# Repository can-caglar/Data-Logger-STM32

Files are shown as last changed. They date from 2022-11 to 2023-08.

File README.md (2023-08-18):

# Serial Snooper

The Serial Snooper is a UART data logger with automatic baud rate detection, real-time data stamping and a command-line-interface for configuration, running on an STM32F3 microcontroller.

It is utilised in an R&D setting to easily capture logs from devices to speed up catching software and hardware bugs.

<i> This project started out as a submission for the final project in the course "Making Embedded Systems" by Elecia White, and evolved into a complete functional product used professionally. The report for the project submitted to the course can be found [here](https://docs.google.com/document/d/1QN5CVr99LwbAlFGOjgETou2btL8RMqJVu_yTGeXLMHs/edit?usp=sharing). </i>

## The Final Product

<center>
<image src="resource\hw_image_1.jpg">
<i>PCBA Front</i>
<br>
<br>
<image src="resource\hw_image_2.jpg">
<i>PCBA Back</i>
<br>
<br>
</center>

## Description of Operation

1. Plug in USB (5V - resettable fuse limits current to 500mA incase of short circuits damaging the power source).
2. Device powers up, indicated by the green LED.
3. A short moment later, the red LED lights up, indicating that the SD card was successfully initialised.
4. Plug in DB9 cable for the device you wish to snoop. The baud rate will be automatically detected.
5. The yellow LED will toggle for every character received.
6. The blue LED will toggle for every successful SD card write.
7. When ready, power down the device by removing the USB cable and remove the SD card.

## Schematic

<center>
<image src="HardwareDesign\hardwareImages_v1\schematic_png.PNG">
<i>Partial schematic. At the heart of the device is a STM32F303 microcontroller.</i>
</center>
<br>

The full hardware schematic can be found on [Github](HardwareDesign/hardwareImages_v1/serial_snooper_schematic.pdf).

## Design Block Diagram

<center>
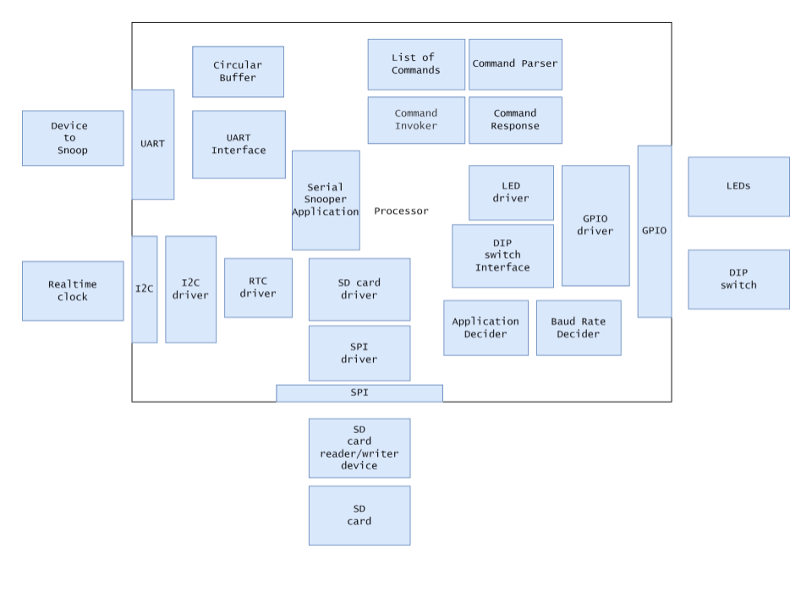
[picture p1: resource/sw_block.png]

<i>Software Block Diagram</i>
</center>

## Prototype

A prototype board was created to aid development.

Headers have been soldered to a perforated board. A mixture of wire wrapping and soldering used for the connections.

### The working prototype

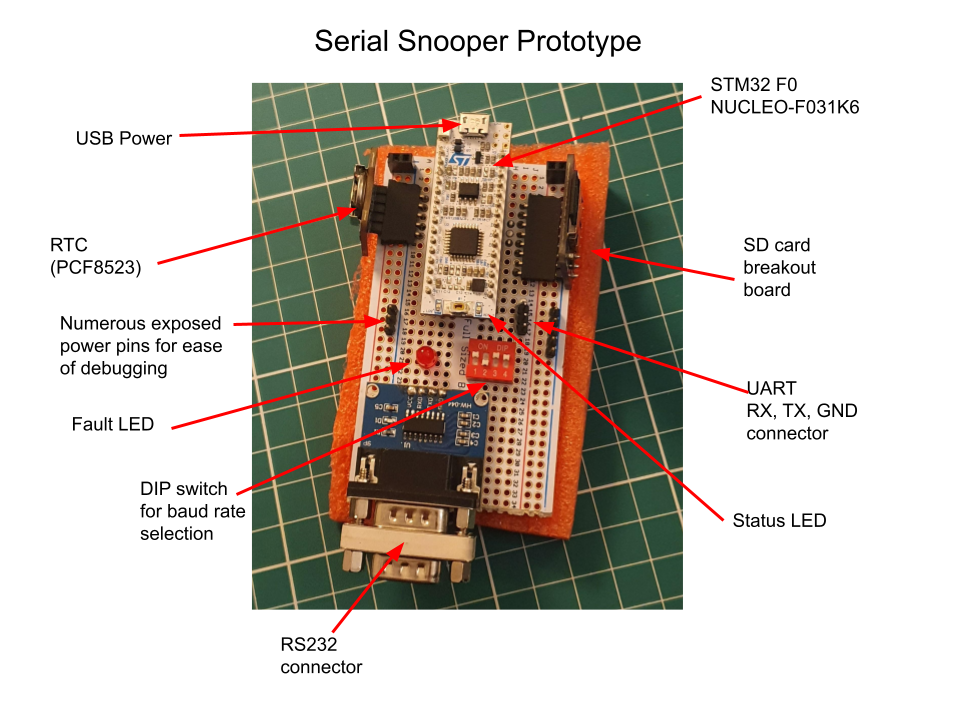
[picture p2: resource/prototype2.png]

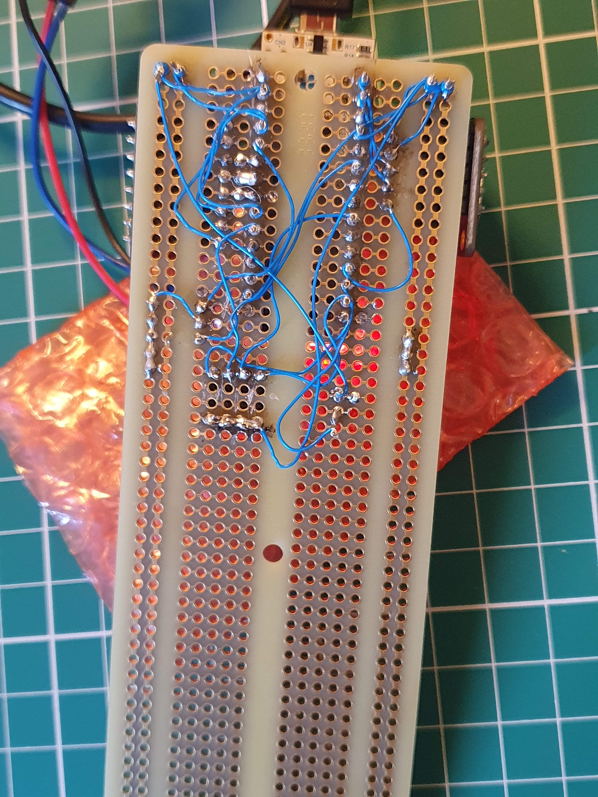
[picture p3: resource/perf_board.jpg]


### Pinouts

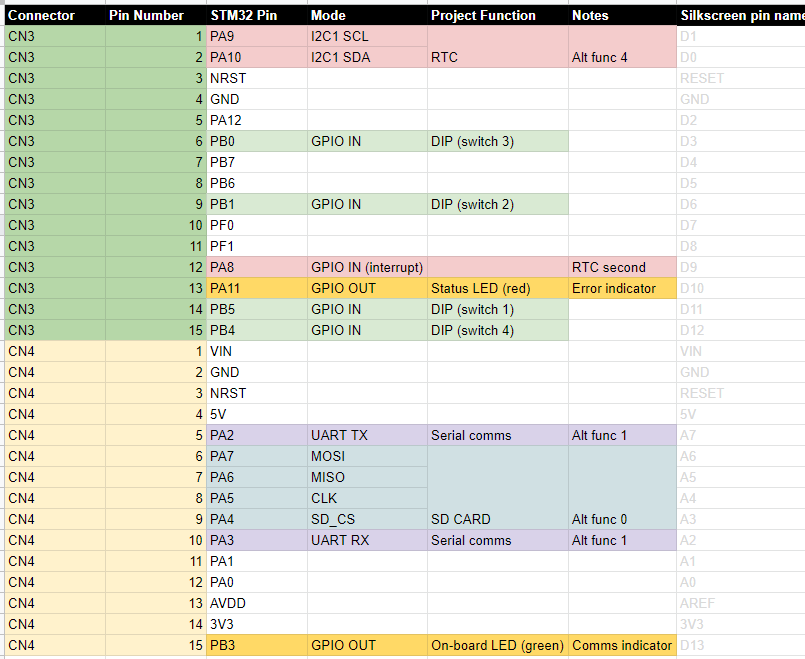
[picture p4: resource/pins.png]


# Demo 

All demonstrations below are from the prototype device using the software in this repository.

## Command Line Interface (CLI)

The CLI is used to:

- Ascertain the software version number
- Send commands:
  - Get DIP switch setting.
  - Get the current time.
  - Set the current time.

For example:
<center>
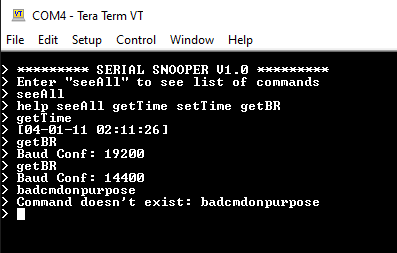
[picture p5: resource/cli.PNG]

</center>

## Example Data Saved on SD Card

The received data is timestamped and saved to the SD card. The filesystem being used is Fatfs (middleware software for this was provided by STM32 Cube).

In the example below, nearly 30,000 characters were sent over the course of 68 seconds (at 115200 BR) and all data was transferred successfully.

*(The text file below is generated by the Serial Snooper and can be found as resource/example_log.TXT)*

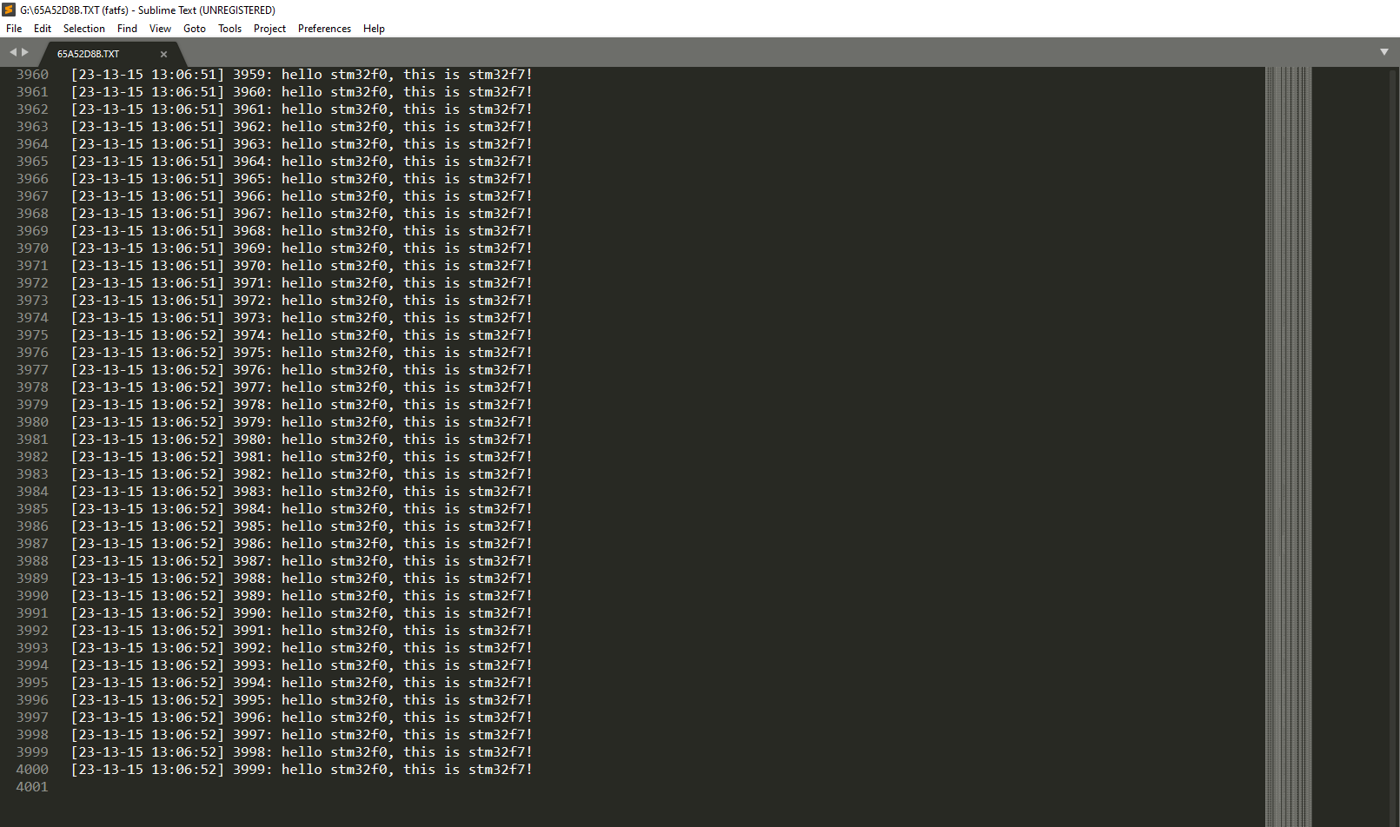
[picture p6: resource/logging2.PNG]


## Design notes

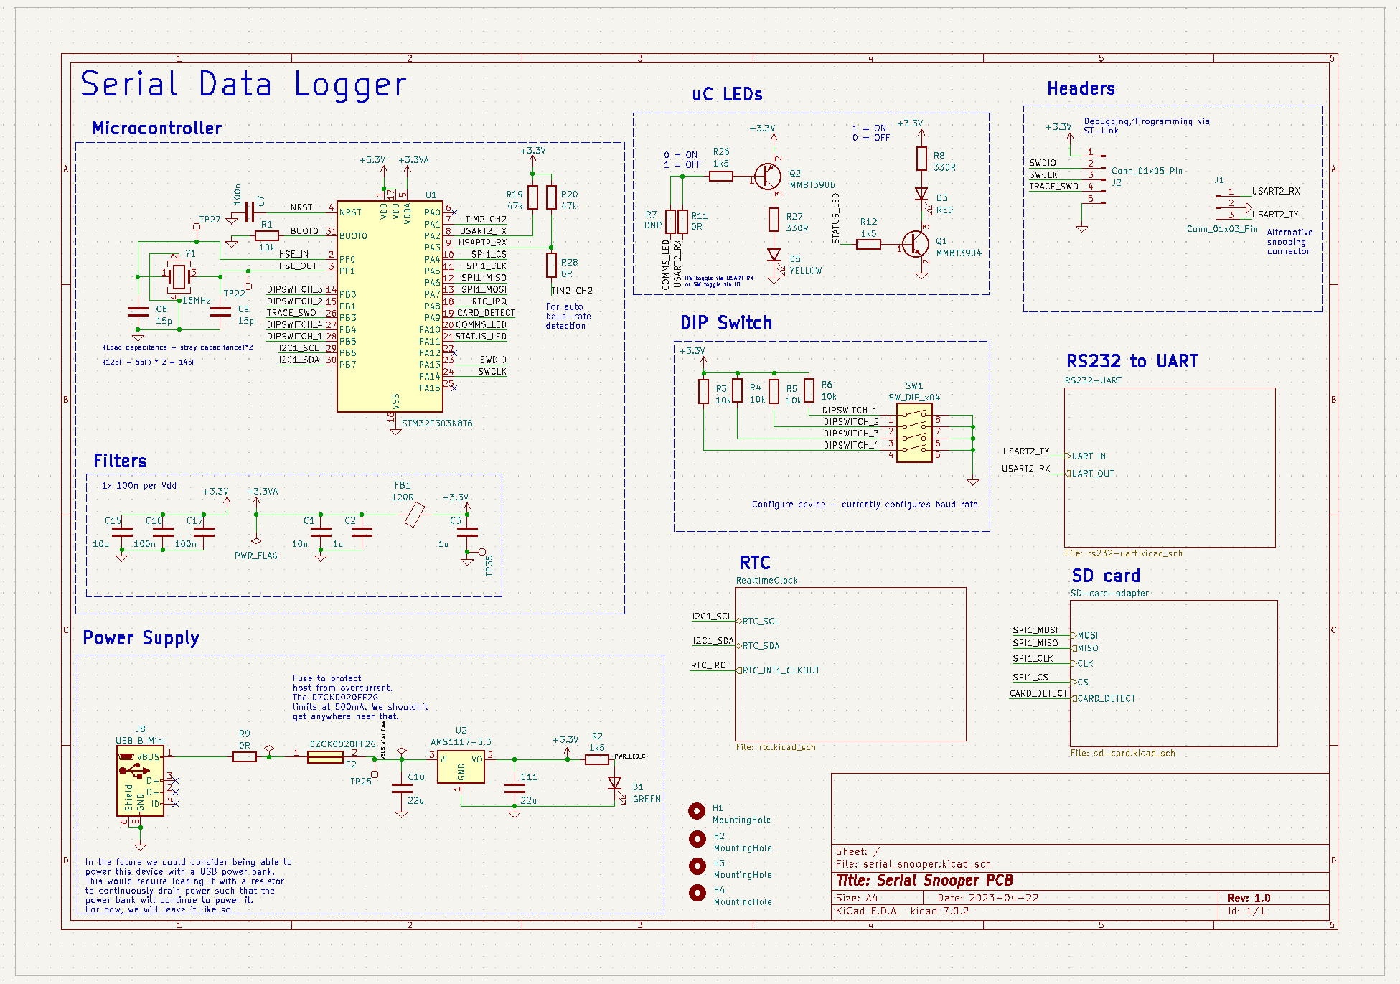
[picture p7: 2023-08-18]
HardwareDesign/hardwareImages_v1/schematic_png.PNG

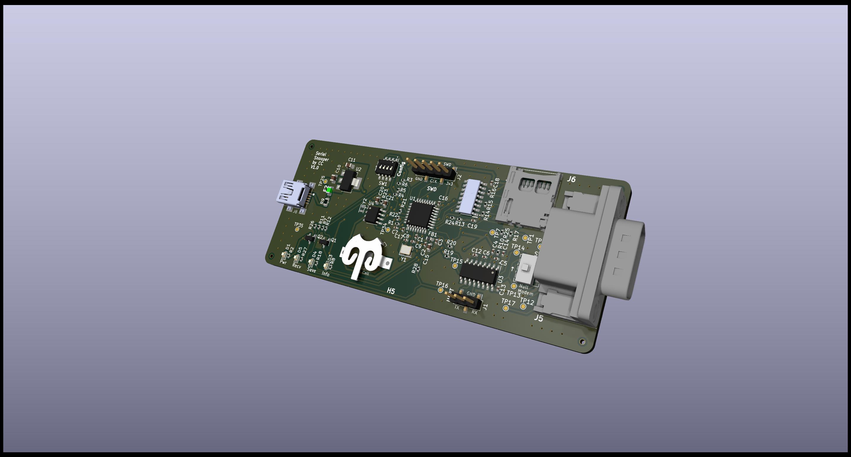
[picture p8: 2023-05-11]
HardwareDesign/hardwareImages_v1/serial_snooper_physical_board.jpg

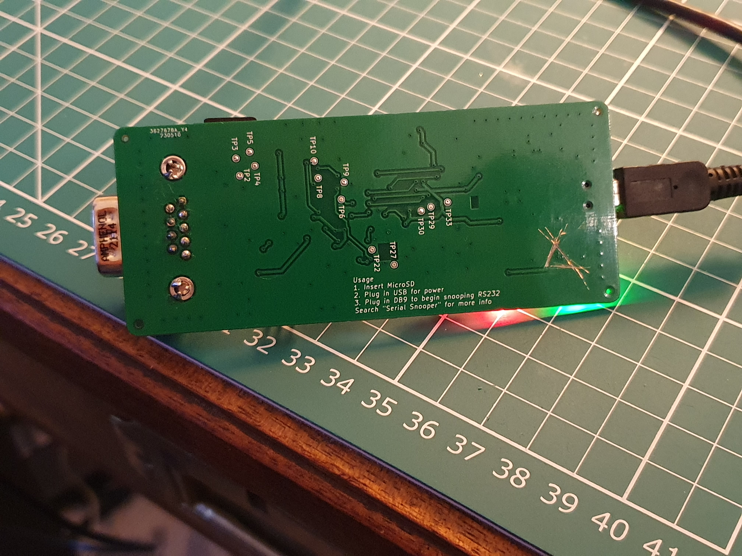
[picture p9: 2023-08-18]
resource/hw_image_2.jpg

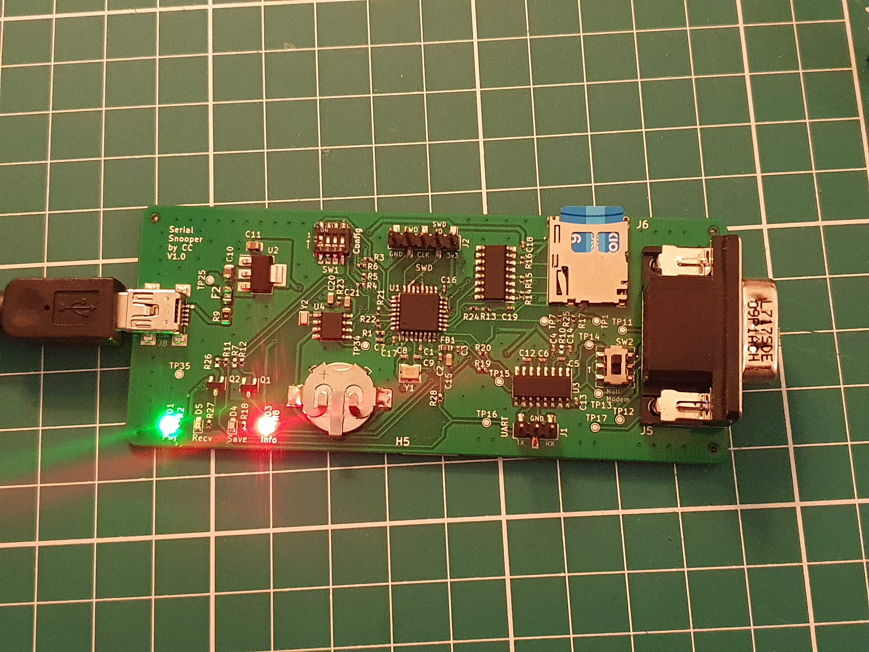
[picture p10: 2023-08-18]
resource/hw_image_1.jpg

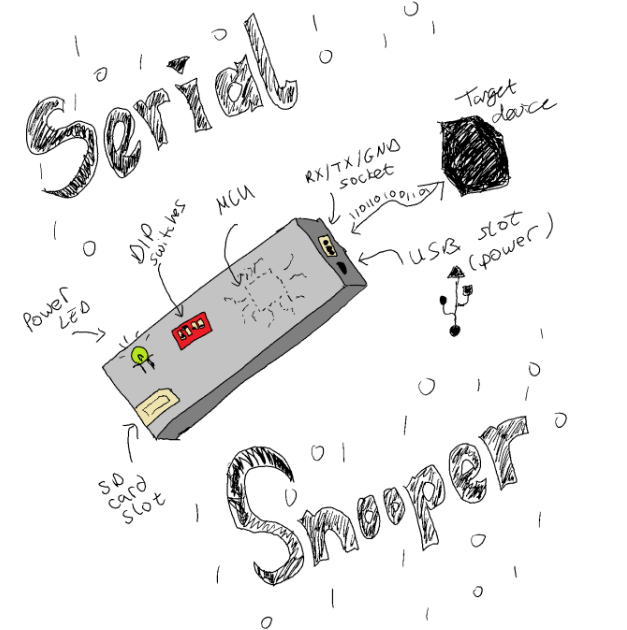
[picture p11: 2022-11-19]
resource/serial_snooper.png

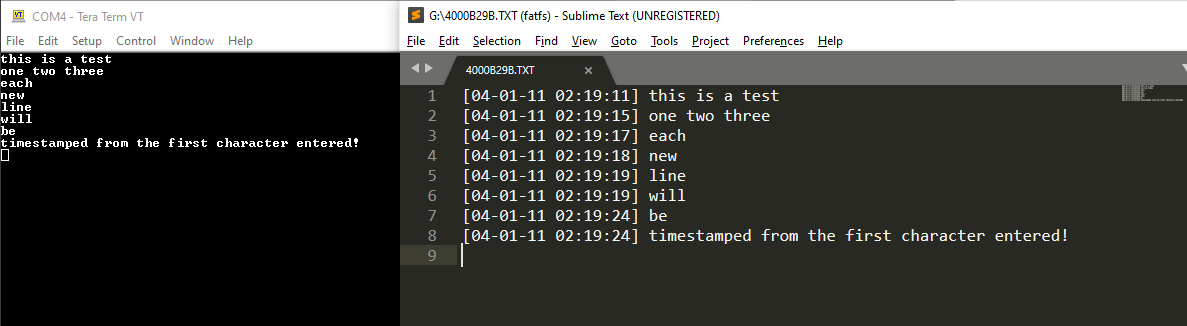
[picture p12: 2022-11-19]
resource/logging.PNG

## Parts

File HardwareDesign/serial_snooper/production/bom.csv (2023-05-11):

Designator | Footprint | Quantity | Value | LCSC Part #
C1 | 0402 | 1 | 10n
C10, C11 | 0805 | 2 | 22u
C12, C13, C14, C16, C17, C18, C19, C4, C5, C6, C7 | 0402 | 11 | 100n
C15, C20, C21 | 0603 | 3 | 10u
C2, C3 | 0402 | 2 | 1u
C8, C9 | 0402 | 2 | 15p
D1 | 0603 | 1 | GREEN
D3 | 0603 | 1 | RED
D4 | 0603 | 1 | RED_SD
D5 | 0603 | 1 | YELLOW
F2 | FUSC2214X100N | 1 | 0ZCK0020FF2G
FB1 | 0603 | 1 | 120R
H1, H2, H3, H4 | ToolingHole | 4 | MountingHole
H5 | 2894 | 1 | 2894
IC1 | SOIC127P600X175-16N | 1 | 74HC4050D,653 | C43181
J1 | PinHeader_1x03_P2.54mm_Vertical_SMD_Pin1Left | 1 | Conn_01x03_Pin | C5160786
J2 | PinHeader_1x05_P2.54mm_Vertical_SMD_Pin1Left | 1 | Conn_01x05_Pin
J5 | L717SDE09P1ACH | 1 | L717SDE09P1ACH
J6 | 5025700893 | 1 | Micro_SD_Card_Det1 | C429846
J8 | USB-MINI-10033526-N3212LF | 1 | USB_B_Mini | C428494
Q1 | SOT-23 | 1 | MMBT3904
Q2 | SOT-23 | 1 | MMBT3906
R1, R21, R22, R3, R4, R5, R6 | 0402 | 7 | 10k
R10, R7 | 0402 | 2 | DNP
R11, R24, R25, R28 | 0402 | 4 | 0R
R12, R18, R2, R23, R26 | 0402 | 5 | 1k5
R13, R14, R15, R16, R17, R19, R20 | 0402 | 7 | 47k
R27, R8 | 0402 | 2 | 330R
R9 | 0805 | 1 | 0R
SW1 | SW_DIP_SPSTx04_Slide_Omron_A6H-4101_W6.15mm_P1.27mm | 1 | SW_DIP_x04
SW2 | DPDT-SMD-MS-22D28G2-B | 1 | SW_DPDT_x2 | C2939266
TP1, TP10, TP11, TP12, TP13, TP14, TP15, TP16, TP17, TP2, TP22, TP25, TP27, TP29, TP3, TP30, TP33, TP34, TP35, TP4, TP5, TP6, TP7, TP8, TP9 | TestPoint_Pad_D1.0mm | 25 | TestPoint
U1 | LQFP-32_7x7mm_P0.8mm | 1 | STM32F303K8T6 | C118318
U2 | SOT-223-3_TabPin2 | 1 | AMS1117-3.3 | C351784
U3 | SOIC-16_3.9x9.9mm_P1.27mm | 1 | MAX3232 | C193666
U4 | SOIC-8_3.9x4.9mm_P1.27mm | 1 | PCF8523T | C2651516
Y1 | Crystal_SMD_3225-4Pin_3.2x2.5mm | 1 | 16MHz | C279610
Y2 | Crystal_SMD_2012-2Pin_2.0x1.2mm | 1 | 32.768 | C252397

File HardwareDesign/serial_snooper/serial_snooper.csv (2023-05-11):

Source: | C:\Users\canca\OneDrive\Study\Embedded\tdd_embedded_systems\on_target_3\HardwareDesign\serial_snooper\serial_snooper.kicad_sch
Date: | 08/05/2023 15:58:42
Tool: | Eeschema 7.0.2
Generator: | C:\Program Files\KiCad\7.0\bin\scripting\plugins/bom_csv_grouped_by_value_with_fp.py
Component Count: | 101
Ref | Qnty | Value | Cmp name | Footprint | Description | Vendor | DNP
C1 | 1 | 10n | C | Capacitor_SMD:C_0402_1005Metric | Unpolarized capacitor
C2, C3 | 2 | 1u | C | Capacitor_SMD:C_0402_1005Metric | Unpolarized capacitor
C4, C5, C6, C7, C12, C13, C14, C16, C17, C18, C19 | 11 | 100n | C | Capacitor_SMD:C_0402_1005Metric | Unpolarized capacitor
C8, C9 | 2 | 15p | C | Capacitor_SMD:C_0402_1005Metric | Unpolarized capacitor
C10, C11 | 2 | 22u | C | Capacitor_SMD:C_0805_2012Metric | Unpolarized capacitor
C15, C20, C21 | 3 | 10u | C | Capacitor_SMD:C_0603_1608Metric | Unpolarized capacitor
D1 | 1 | GREEN | LED | LED_SMD:LED_0603_1608Metric | Light emitting diode
D3 | 1 | RED | LED | LED_SMD:LED_0603_1608Metric | Light emitting diode
D4 | 1 | RED_SD | LED | LED_SMD:LED_0603_1608Metric | Light emitting diode
D5 | 1 | YELLOW | LED | LED_SMD:LED_0603_1608Metric | Light emitting diode
F2 | 1 | 0ZCK0020FF2G | 0ZCK0020FF2G | MyLibrary:FUSC2214X100N | BEL FUSE - 0ZCK0020FF2G - FUSE, RESETTABLE PTC, 9VDC, 0.2A, SMD
FB1 | 1 | 120R | FerriteBead | Inductor_SMD:L_0603_1608Metric | Ferrite bead
H1, H2, H3, H4 | 4 | MountingHole | MountingHole | MountingHole:MountingHole_2.2mm_M2 | Mounting Hole without connection
H5 | 1 | 2894 | 2894 | MyLibrary:2894 | Coin Cell Battery Holders CR1220 COIN CELL SMT RETAINER
IC1 | 1 | 74HC4050D,653 | 74HC4050D,653 | MyLibrary:SOIC127P600X175-16N | NEXPERIA - 74HC4050D,653 - LEVEL SHIFTER, NON INVERTING, SOIC-16
J1 | 1 | Conn_01x03_Pin | Conn_01x03_Pin | Connector_PinHeader_2.54mm:PinHeader_1x03_P2.54mm_Vertical_SMD_Pin1Left | Generic connector, single row, 01x03, script generated
J2 | 1 | Conn_01x05_Pin | Conn_01x05_Pin | Connector_PinHeader_2.54mm:PinHeader_1x05_P2.54mm_Vertical_SMD_Pin1Left | Generic connector, single row, 01x05, script generated
J5 | 1 | L717SDE09P1ACH | L717SDE09P1ACH | MyLibrary:L717SDE09P1ACH | Dsub, Stamped Signal 3A, Right Angle PCB Through Hole, FP=10.40mm (0.409in), Row Pitch 2.54mm, 9 Pin, Flash Gold, Bright Tin Shell+Grounding Dimples, 3.05mm (0.120in) Clear Hole, Ground Tab with Boardlock
J6 | 1 | Micro_SD_Card_Det1 | Micro_SD_Card_Det1 | MyLibrary:5025700893 | Micro SD Card Socket with one card detection pin
J8 | 1 | USB_B_Mini | USB_B_Mini | MyLibrary:USB-MINI-10033526-N3212LF | USB Mini Type B connector
Q1 | 1 | MMBT3904 | MMBT3904 | Package_TO_SOT_SMD:SOT-23 | 0.2A Ic, 40V Vce, Small Signal NPN Transistor, SOT-23
Q2 | 1 | MMBT3906 | MMBT3906 | Package_TO_SOT_SMD:SOT-23 | -0.2A Ic, -40V Vce, Small Signal PNP Transistor, SOT-23
R1, R3, R4, R5, R6 | 5 | 10k | R | Resistor_SMD:R_0402_1005Metric | Resistor
R2, R12, R18, R23, R26 | 5 | 1k5 | R | Resistor_SMD:R_0402_1005Metric | Resistor
R7, R10 | 2 | DNF | R | Resistor_SMD:R_0402_1005Metric | Resistor
R8, R27 | 2 | 330R | R | Resistor_SMD:R_0402_1005Metric | Resistor
R9 | 1 | 0R | R | Resistor_SMD:R_0805_2012Metric | Resistor
R11, R24, R25, R28 | 4 | 0R | R | Resistor_SMD:R_0402_1005Metric | Resistor
R13, R14, R15, R16, R17, R19, R20 | 7 | 47k | R | Resistor_SMD:R_0402_1005Metric | Resistor
R21, R22 | 2 | 10K | R | Resistor_SMD:R_0402_1005Metric | Resistor
SW1 | 1 | SW_DIP_x04 | SW_DIP_x04 | Button_Switch_SMD:SW_DIP_SPSTx04_Slide_Omron_A6H-4101_W6.15mm_P1.27mm | 4x DIP Switch, Single Pole Single Throw (SPST) switch, small symbol
SW2 | 1 | SW_DPDT_x2 | SW_DPDT_x2 | MyLibrary:DPDT-SMD-MS-22D28G2-B | Switch, dual pole double throw, separate symbols
TP1, TP2, TP3, TP4, TP5, TP6, TP7, TP8, TP9, TP10, TP11, TP12, TP13, TP14, TP15, TP16, TP17, TP22, TP25, TP27, TP29, TP30, TP33, TP34, TP35 | 25 | TestPoint | TestPoint | TestPoint:TestPoint_Pad_D2.0mm | test point
U1 | 1 | STM32F303K8T6 | STM32F303K8Tx | Package_QFP:LQFP-32_7x7mm_P0.8mm | STMicroelectronics Arm Cortex-M4 MCU, 64KB flash, 16KB RAM, 72 MHz, 2.0-3.6V, 25 GPIO, LQFP32
U2 | 1 | AMS1117-3.3 | AMS1117-3.3 | Package_TO_SOT_SMD:SOT-223-3_TabPin2 | 1A Low Dropout regulator, positive, 3.3V fixed output, SOT-223
U3 | 1 | MAX3232 | MAX3232 | Package_SO:SOIC-16_3.9x9.9mm_P1.27mm | 3.0V to 5.5V, Low-Power, up to 1Mbps, True RS-232 Transceivers Using Four 0.1μF External Capacitors
U4 | 1 | PCF8523T | PCF8523T | Package_SO:SOIC-8_3.9x4.9mm_P1.27mm | Realtime Clock/Calendar I2C Interface, SOIC-8
Y1 | 1 | 16MHz | Crystal_GND24 | Crystal:Crystal_SMD_3225-4Pin_3.2x2.5mm | Four pin crystal, GND on pins 2 and 4
Y2 | 1 | 32.768 | Crystal | Crystal:Crystal_SMD_2012-2Pin_2.0x1.2mm | Two pin crystal

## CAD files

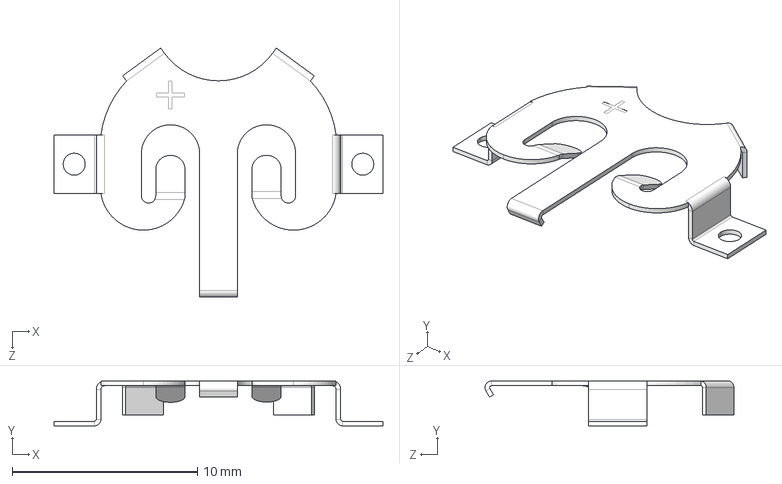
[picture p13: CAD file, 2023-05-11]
HardwareDesign/serial_snooper/CR1220_CASE_LIB_2894/2894/3D/2894.stp
17.8 x 2.42 x 13.5 mm

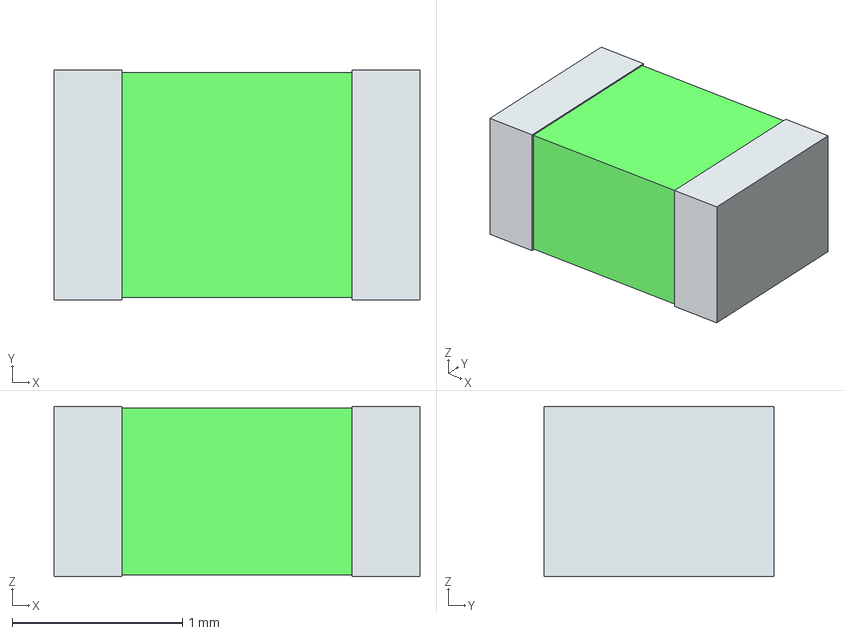
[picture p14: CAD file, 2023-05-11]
HardwareDesign/serial_snooper/LIB_0ZCK0020FF2G/0ZCK0020FF2G/3D/0ZCK0020FF2G.stp
2.15 x 1.35 x 1.00 mm
term1
term2

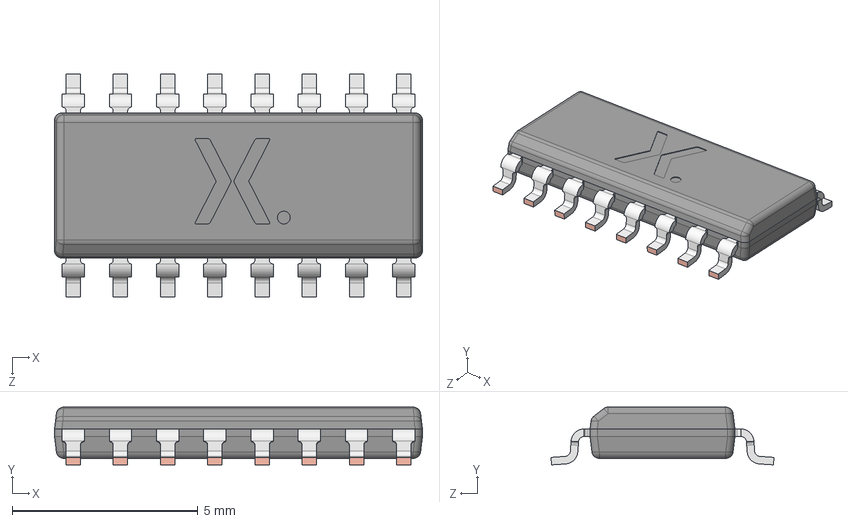
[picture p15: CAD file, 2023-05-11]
HardwareDesign/serial_snooper/LIB_74HC4050D,653/74HC4050D,653/3D/74HC4050D,653.stp
9.90 x 1.56 x 6.00 mm
SOT109-1 lower body
SOT109-1 upper body
SOT109-1 Lead

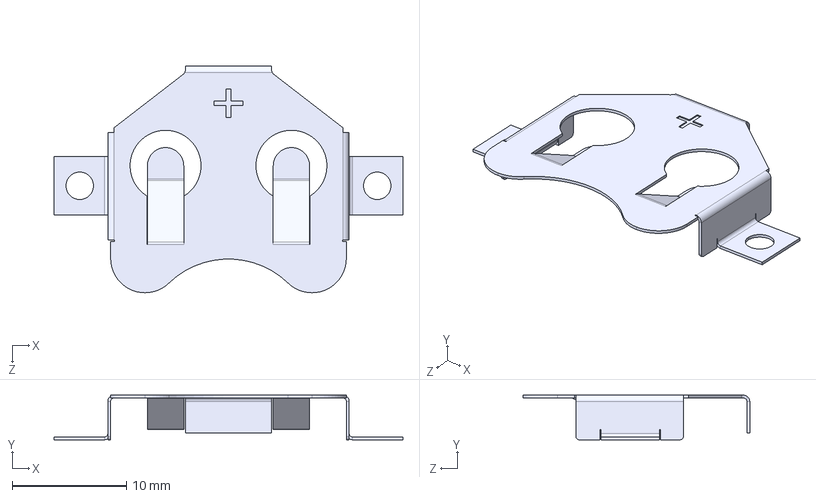
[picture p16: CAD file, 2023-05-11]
HardwareDesign/serial_snooper/LIB_BAT-HLD-003-SMT/BAT-HLD-003-SMT--3DModel-STEP-1.STEP
30.5 x 3.90 x 19.8 mm

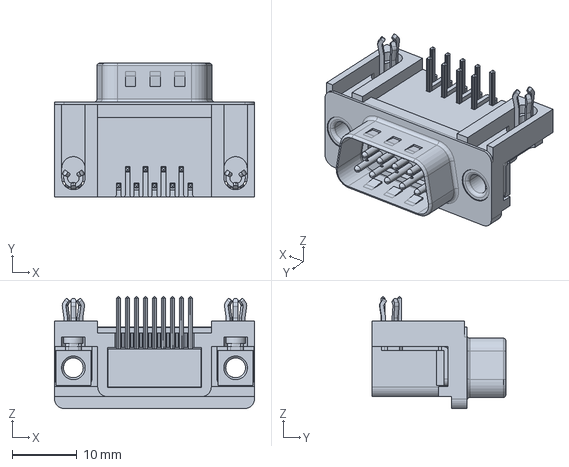
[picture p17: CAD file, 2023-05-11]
HardwareDesign/serial_snooper/LIB_L717SDE09P1ACH/L717SDE09P1ACH/3D/L717SDE09P1ACH.stp
30.8 x 20.6 x 17.3 mm

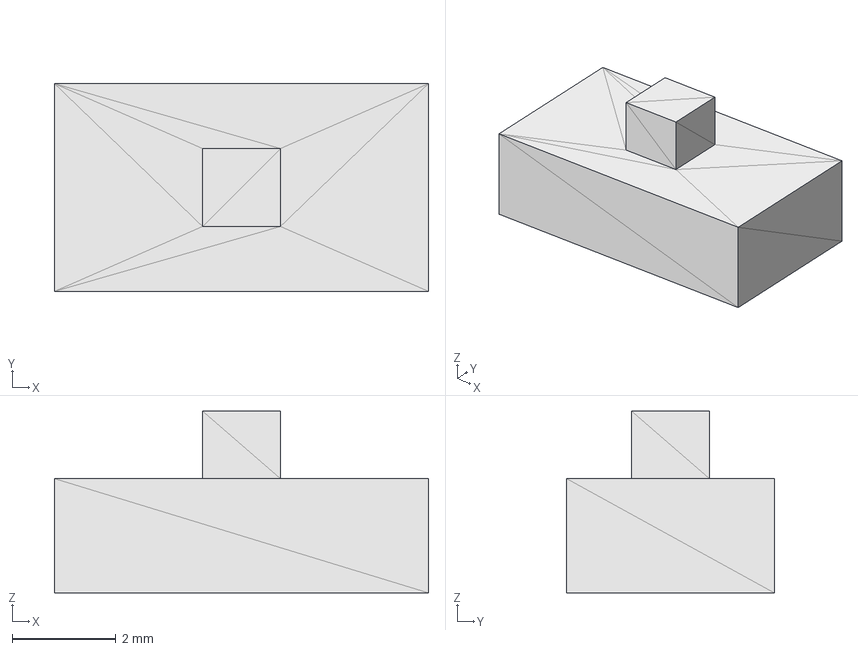
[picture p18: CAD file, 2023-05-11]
HardwareDesign/serial_snooper/DPDT_22D28G2-B/a.step
7.20 x 4.00 x 3.50 mm

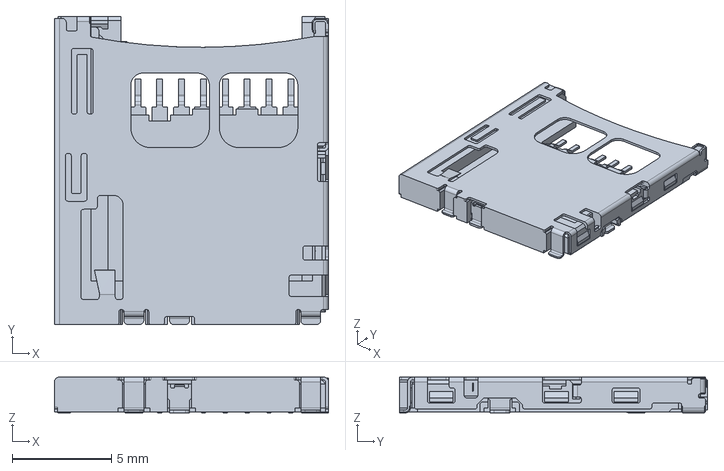
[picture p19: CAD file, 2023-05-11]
HardwareDesign/serial_snooper/LIB_502570-0893/502570-0893/3D/502570-0893.stp
13.8 x 15.5 x 1.80 mm

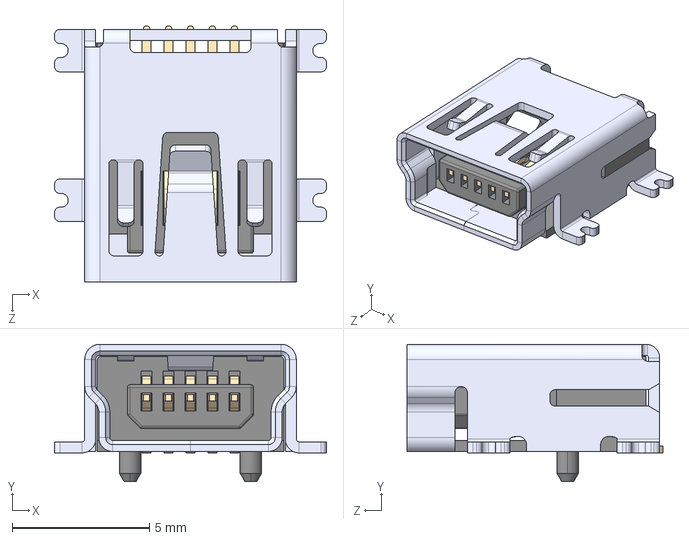
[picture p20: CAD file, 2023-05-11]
HardwareDesign/serial_snooper/USB_Mini/10033526-N3212LF--3DModel-STEP-554624.STEP
9.90 x 5.00 x 9.32 mm

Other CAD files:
HardwareDesign/serial_snooper/DPDT_22D28G2-B/DPDT SW 22D28G2-B.stp
HardwareDesign/serial_snooper/DPDT_22D28G2-B/dpdt_3d.stp
HardwareDesign/serial_snooper/CR1220_CASE_LIB_2894/2894/Allegro/2894.psm
HardwareDesign/serial_snooper/CR1220_CASE_LIB_2894/2894/DEHDL/2894/chips/chips.prt
HardwareDesign/serial_snooper/DPDT_22D28G2-B/DPDT SW 22D28G2-B.stl
HardwareDesign/serial_snooper/LIB_0ZCK0020FF2G/0ZCK0020FF2G/Allegro/fusc2214x100n.psm
HardwareDesign/serial_snooper/LIB_0ZCK0020FF2G/0ZCK0020FF2G/DEHDL/0zck0020ff2g/chips/chips.prt
HardwareDesign/serial_snooper/LIB_502570-0893/502570-0893/Allegro/5025700893.psm
HardwareDesign/serial_snooper/LIB_502570-0893/502570-0893/DEHDL/502570_0893/chips/chips.prt
HardwareDesign/serial_snooper/LIB_74HC4050D,653/74HC4050D,653/Allegro/soic127p600x175-16n.psm
HardwareDesign/serial_snooper/LIB_74HC4050D,653/74HC4050D,653/DEHDL/74hc4050d_653/chips/chips.prt
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

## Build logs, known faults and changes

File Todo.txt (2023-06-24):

***************************************************************************************************************************************************

# Data Logger V2 Tasks:

- [ ] Variable names (namely make MVC pattern more obvious)
- [x] Reduce size of program
- [x] Do not read circ buf if it's empty
- [x] Remove context argument from data holder, it doesn't need it
    - [x] Remove refresh too. and give data if/when requested
- [x] Upgrade uC so we can increase size of buffers
- [x] Understand fatfs better; it seems to buffer internally, 
    so perhaps writing 1 byte at a time is OK for performance
    - Benchmark shows the more we write, the faster the throughput.
- [x] Upgrade processor to one with more RAM.
    - [x] Update processor speed
    - [x] Update SPI speed
    - [x] Increase circular buffer size
    - [x] Update I2C wiring (PB7 SDA, PB6 SCL, AF4)
        - [!] Remove the solder bridge SB16 AND SB18 else I2C and SPI will clash.
    - [...] Remove solder bridge to allow the device to be plugged into the wall
        - Won't work as the current consumption with new processor and code is over 100mA (as per user manual)
        - Going to look into adding a separate connector.
    - [x] Update USART (usart1 -> usart2, new alt func)
    - [x] Check SD card library works
    - [x] Write a benchmarking test for the SD card - what is the write throughput?
        - Sending 1 byte per loop, vs 512, vs 1024, 2048, vs 4096
        - Turn off FF_FS_TINY?
        - Try higher SPI speed
        - Run the test a few times, perhaps 5 times each and get an average
    - [-] Use internal RTC | No VBAT on this particular chip (LQFP32)
        See page 31 LQFP32 pinout of STM32F303x6/x8 Datasheet for this info.
    - [x] Research baud rate detection
        - STM32F0, STM32F3 both have this feature
        - However, it requires the master device to send known bytes at the start.
        - Another way could be to wire RX line to a timer pin 
            with input capture. Take X measurements. 
            Smallest will likely be baud rate.
    - [-] Research the 4Kb of CCM RAM we have on this chip. | Currently do not need to
- [x] Update tests so they pass again with this new chip
- [x] Test circular buffer capacity that is not a power of 2 to make it as large as possible.
- [ ] Run an overnight test with a different SD card- does the buffer overflow?

***************************************************************************************************************************************************

Data logger V3 (current):

V2 behaviour: The Serial Snooper creates a log file on an SD card with a FAT32 file system. It will transfer UART received data 
to a file on the SD card until it reaches a max size. A new file is created when this happens. A new file is also created upon a power cycle.
UART baud rate is currently configured via DIP switches. 

New in V3: 
    - It will write to the same log file even after a power cycle.
        - Need a way to know to re-open the file it was writing to last. Details can change in future easily, as long as architecture is right.
            - Option 1: Since RTC has to work, we can just check the txt file that was written to last:
                - Making assumption that the SD card was only used by SS (if not, we risk writing to a log file not created by us)
            - Option 2: Save current log file name onto the SD card and retrieve on power cycle. If it doesn't exist, make a new one.
                - This will likely need to be expanded in the future to save more details that retain on a power cycle.
                - I.e. a file that holds a structure of data that needs to be parsed to get the information needed
            - Need an abstraction for log file creator. Handles opening a log file, let it handle where and what name.
            - Only 1 log file open at a time.
    - Make system behaviour more defined: Error handling:
        - We are making many assumptions. If any are not met, system may perform in inadvertant ways. Let's limit behaviour by calling error
            handling code if some conditions are not met.
        - Flash LED N number of times where N is number of LED blinks followed by a long delay, indefinitely.
        - Errors:
            - RTC not working, throw error - go to error handling code. 
            - If SD card not initialised, throw error - go to error handling code. Flash LED N number of times.
            - If SD card full

    - The name given to the log files: currently it's based on RTC time- an 8 digit unit timestamp in hex.
    - The naming convention of iterative log files: currently it's based on RTC but if RTC doesn't work it will keep opening the same 
        file even if max size reached. - solved by error handling code which won't let system work without RTC (for now)
    - Maximum number of log files - currently no maximum.
    - Whether or not there is a Maximum
    - What to do when the maximum log files is reached - shall be handled by error handling.
    - What happens if SD card contains too many files already, is full, or has files with our naming conventions?

- [x] Continue writing to the same file even after a power cycle
    - This gives the serial snooper a more predictable behaviour
    - Reduces likelihood of creating too many files on the SD card which may cause issues when reading it from a PC
    - [ ] Add system to retain information after power cycling and load this information on start-up.
- [ ] Add ability to configure the Serial Snooper via a config file on the SD card.
    - Max files
    - File circular buffer (oldest file gets re-written)
- [x] Auto-baud rate detection
    - Do this but fake the hardware dependency as I understand it
    - The technique is to connect uart input to a timer and interrupt on an edge
    - Look for the smallest time between the interrupts
        - to make it noise-proof, take a tally of these over a short period of time
    - this time will be the period

***************************************************************************************************************************************************

Data logger V4:

Behaviour: 
- We want the system to work even without an RTC.
- Let SD card be used by other things, not just SS?
- New configurable setting: Timestamping can be switched on or off. This is configured in the CLI and retained on the SD card.

Option 1:
    The logfiles should have a name that gives away which logfile was written to last.
        - The software can then parse the file names to get the last file.
        - This decouples the file naming from the RTC where in future if we want the system to work even if RTC power dies, it will work
        - Example: sslog000.txt, sslog001.txt, sslog002.txt ... sslog999.txt
        - Need an abstraction for the SD card storage itself where it knows which files are there, which configs etc?

***************************************************************************************************************************************************

Notes:
    - Where the log files are stored on the SD card: currently it's stored in root
        - abstractions:
            - which log file to write to
                - naming convention of log file: random? sequential?
            - directory of log file

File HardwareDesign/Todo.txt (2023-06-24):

- [x] Capture schematic
    - [x] Same as prototype version but without on-board ST link
        - [x] LED to indicate power
        - [x] LED to indicate receive (rx)
        - [x] LED to indicate transmit (tx)
        - [x] LED to indicate errors
        - [x] SWDIO for programming it
        - [x] Test points for comms
        - [x] Test points for GND
        - [x] USB for power only
        - [-] Power also from external supply?
        - [x] Current consumption header
        - [x] Pull up UART / SPI / I2C lines
        - [x] Use fuse for overcurrent protection
        - [x] Crystal, or crystal oscillator for stm32 uc
        - [x] Pins to expose UART
        - [x] USB mini
- [x] Draw layout
    - [-] Silkscreen
        - On the back, explain how to use it
- [x] Order
- [ ] Board bring-up
    - [x] Ensure 3v3 power led to lights up | there was an issue with the mask on the back plane causing a short (maybe forgot to do refill before
        generating gerbers). fixed it by cutting traces around the short.
    - [x] Program and debug the device | bad solder joints on the SWDIO and 3v3 line on the stm32 was causing issues. now it programs fine.
        - note: no reset line, but the system still seems to respect the reset button on Keil and start debugging from the beginning.
        - note2: the only pins connected are GND, SWDIO, SWCLK and 3v3 (to ST link pin 1 (Target Vcc).
    - [x] Set RTC time
        - [x] RTC doesn't retain time sometimes and resets, why? | the GND plane wasn't making contact with the battery - added
            solder there and now it's ok.
    - [ ] The "Save" LED (blue) doesn't light up - resistor val too high?
    - [x] Check soldering for the DIP switch - always returning 0xFF | was a bad solder joint
- [x] Code changes:
    - [x] No-pull on the dip switch I/O

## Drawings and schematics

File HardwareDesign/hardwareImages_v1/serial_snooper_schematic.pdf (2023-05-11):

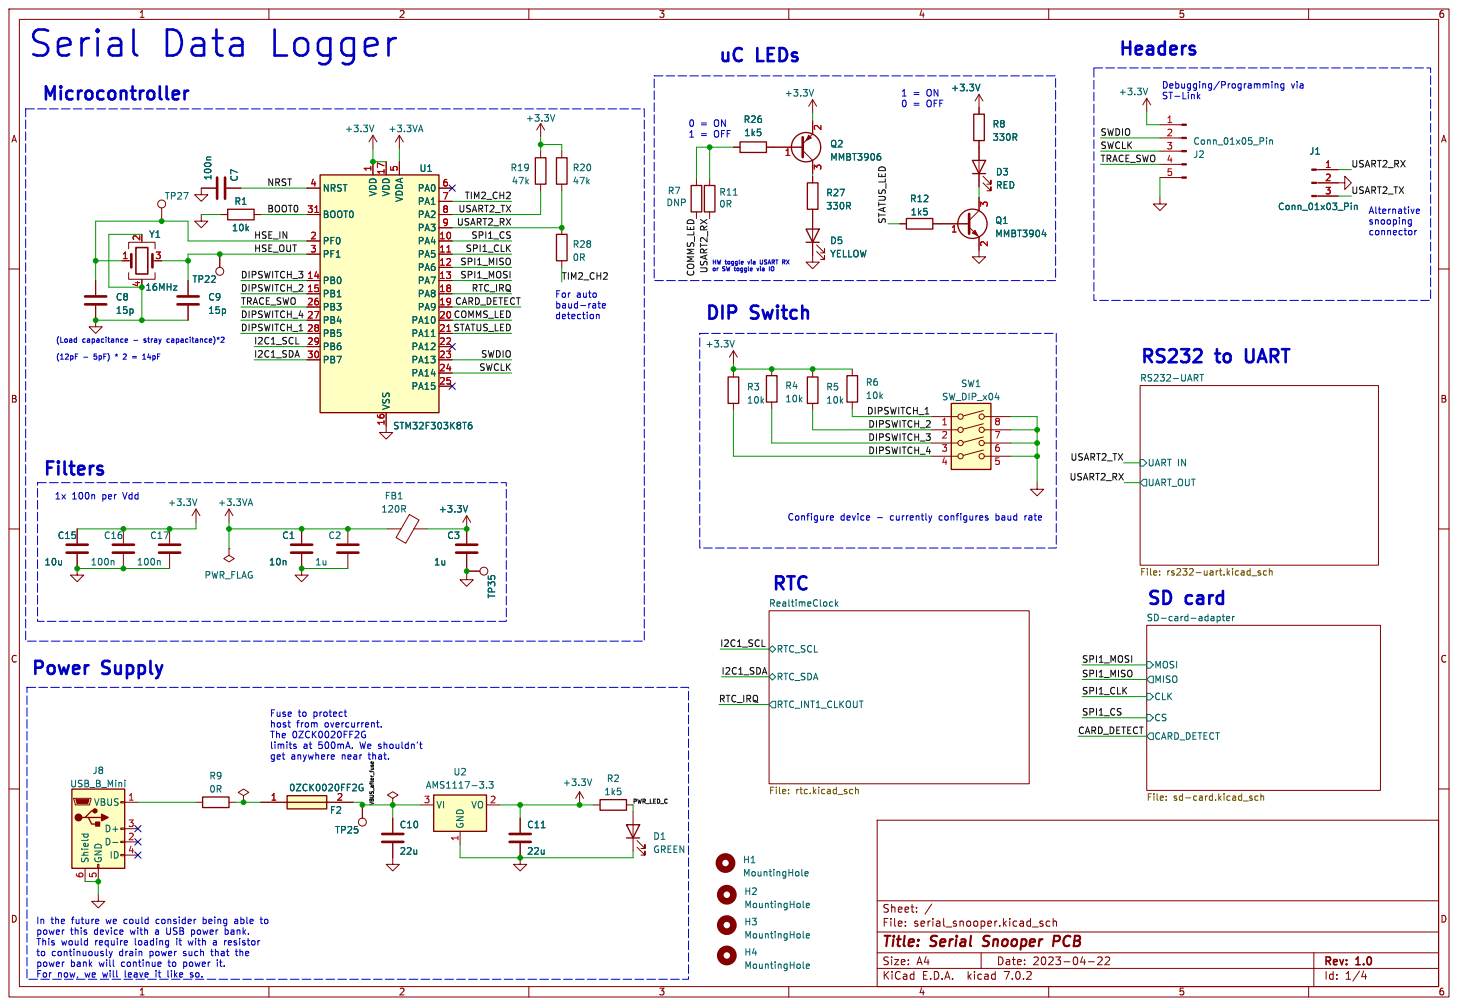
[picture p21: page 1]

1 = OFF Serial Data Logger

1 PA4 10 PA5 11 PA6 12 PA7 13 PB0 14 PB1 15 VSS 16 VDD 17 PA8 18 PA9 19 PF0 2 PA10 20 PA11 21 PA12 22 PA13 23 PA14 24 PA15 25 PB3 26 PB4 27 PB5 28 PB6 29 PF1 3 PB7 30 BOOT0 31 NRST 4 VDDA

HW toggle via USART RX

RS232-UART
CLK CSCARD_DETECT SD-card-adapter File: sd-card.kicad_sch UART_OUT UART IN

limits at 500mA. We shouldn't get anywhere near that. C1

File: rs232-uart.kicad_sch RTC_SCL RTC_INT1_CLKOUT RTC_SDA RealtimeClock File: rtc.kicad_sch

Fuse to protect host from overcurrent. The 0ZCK0020FF2G

In the future we could consider being able to
power this device with a USB power bank. This would require loading it with a resistor

Id: 1/4 Title: Serial Snooper PCB

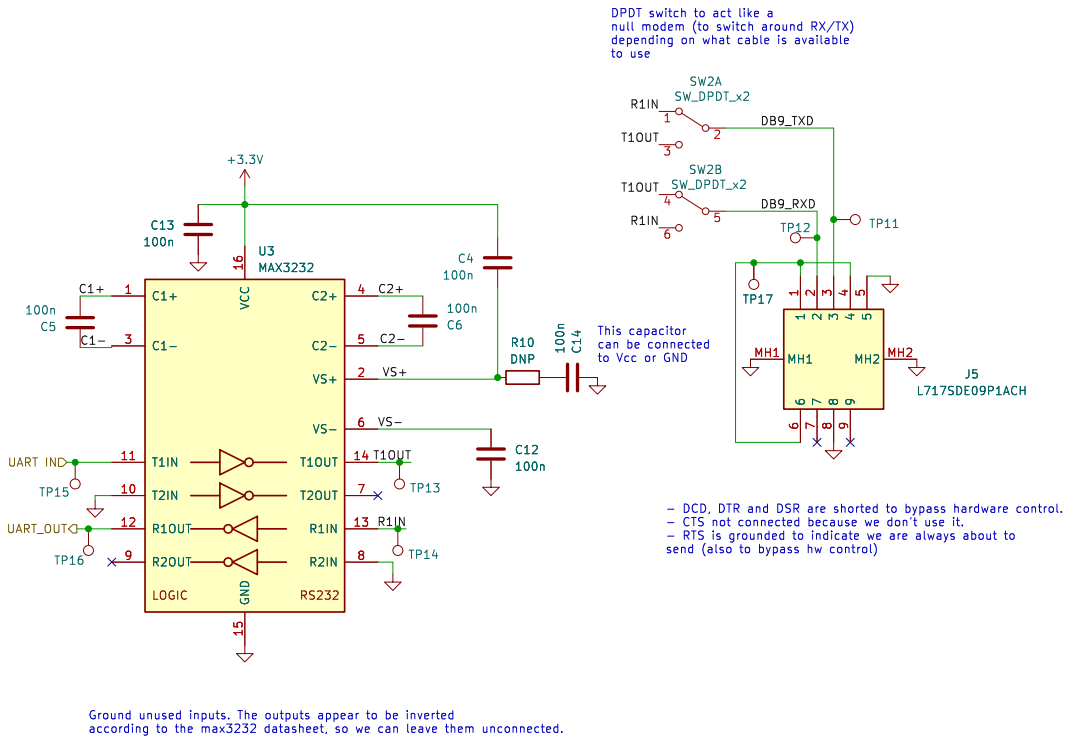
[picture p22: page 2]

send (also to bypass hw control) DPDT switch to act like a
null modem (to switch around RX/TX)
to use This capacitor can be connected

to Vcc or GND

Id: 2/4 Title: File: rs232-uart.kicad_sch Sheet: /RS232-UART/

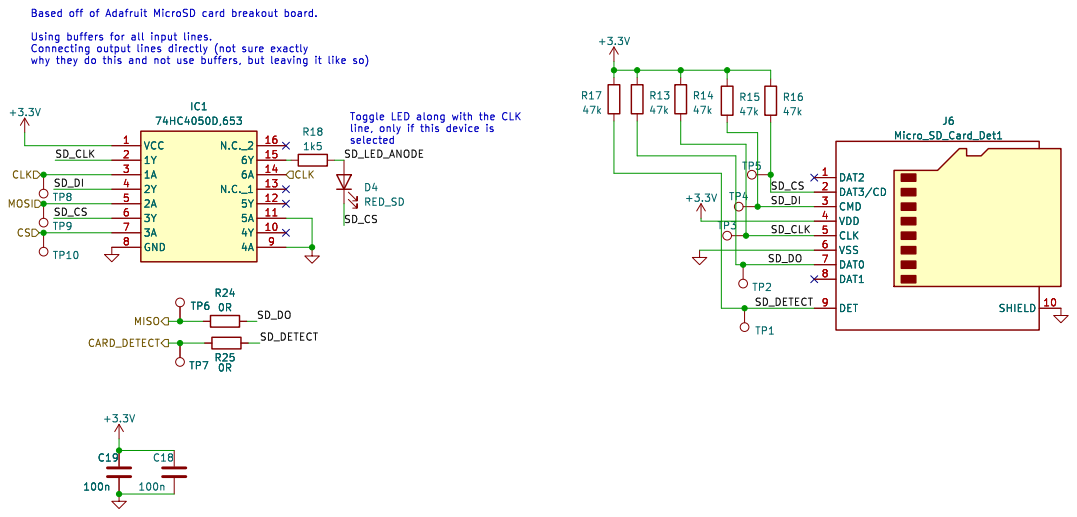
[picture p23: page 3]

Toggle LED along with the CLK
line, only if this device is

Id: 3/4 Title: File: sd-card.kicad_sch Sheet: /SD-card-adapter/

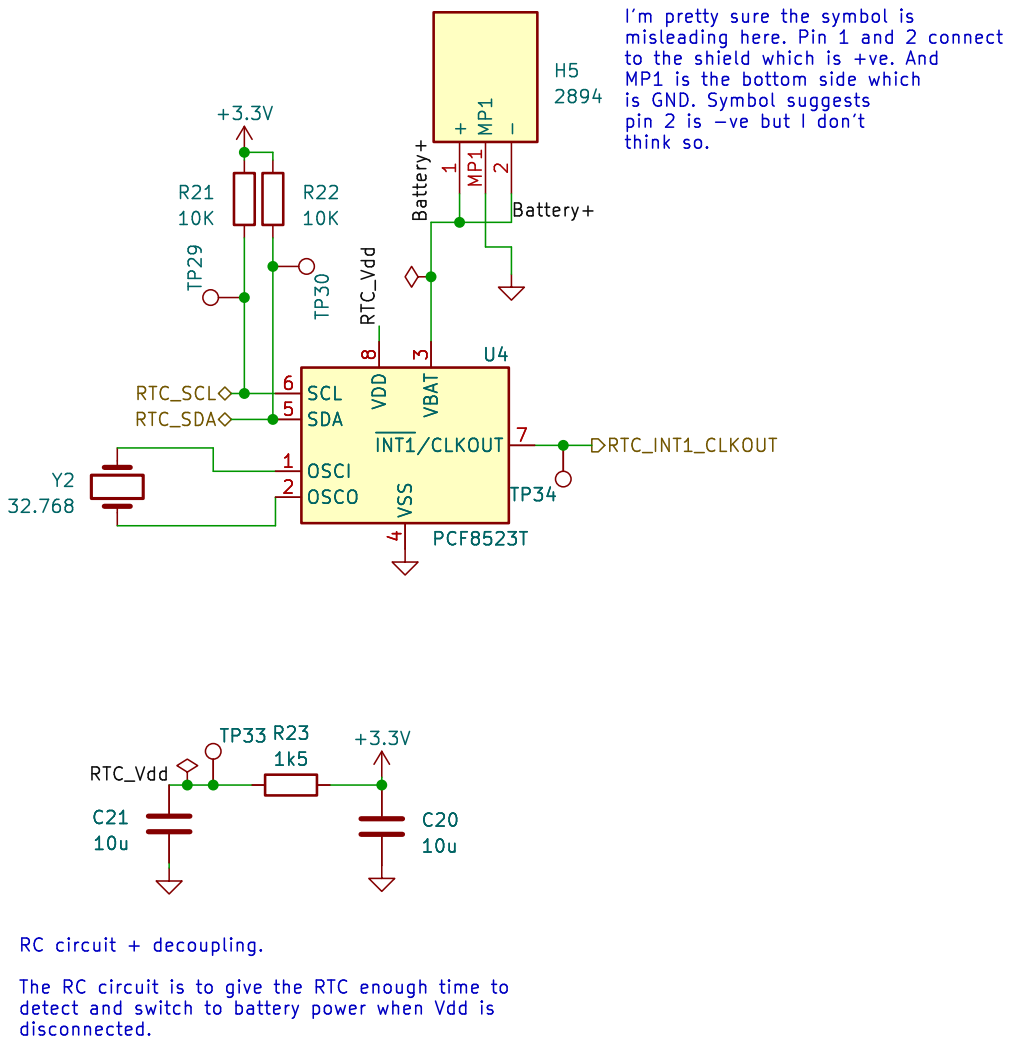
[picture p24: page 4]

to the shield which is +ve. And MP1 is the bottom side which

is GND. Symbol suggests pin 2 is -ve but I don't

8U4 PCF8523T TP29 TP30 TP34 RTC_SCL RTC_SDA RTC_INT1_CLKOUT RTC_Vdd Battery+ Battery+ RTC_Vdd RC circuit + decoupling. The RC circuit is to give the RTC enough time to

detect and switch to battery power when Vdd is disconnected.

Id: 4/4 Title: File: rtc.kicad_sch Sheet: /RealtimeClock/

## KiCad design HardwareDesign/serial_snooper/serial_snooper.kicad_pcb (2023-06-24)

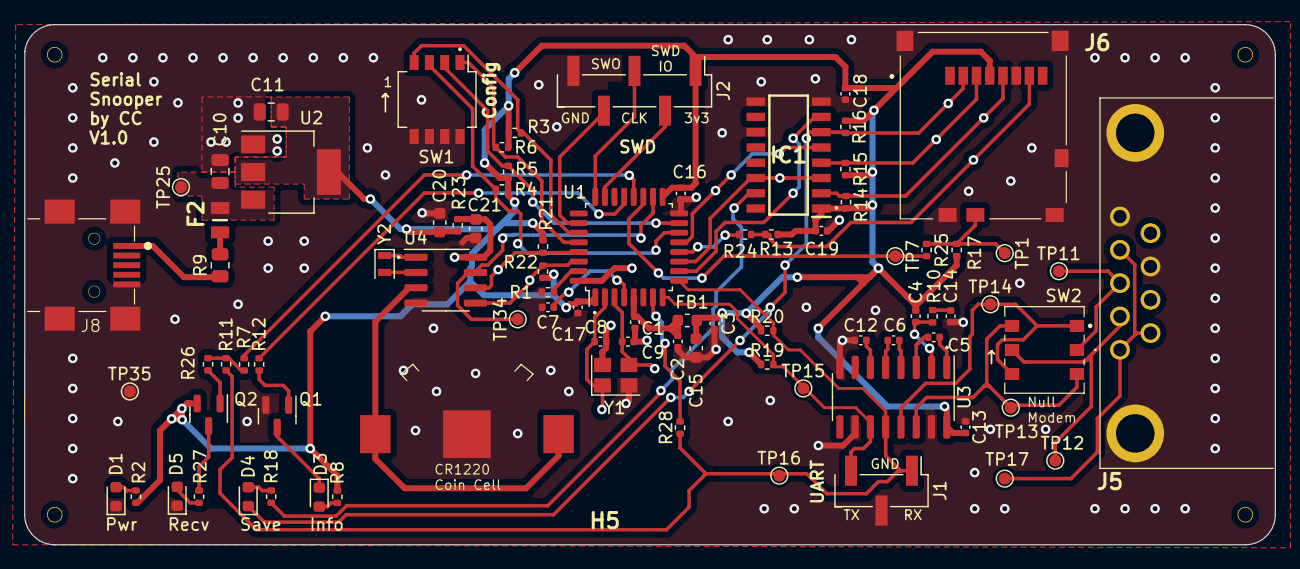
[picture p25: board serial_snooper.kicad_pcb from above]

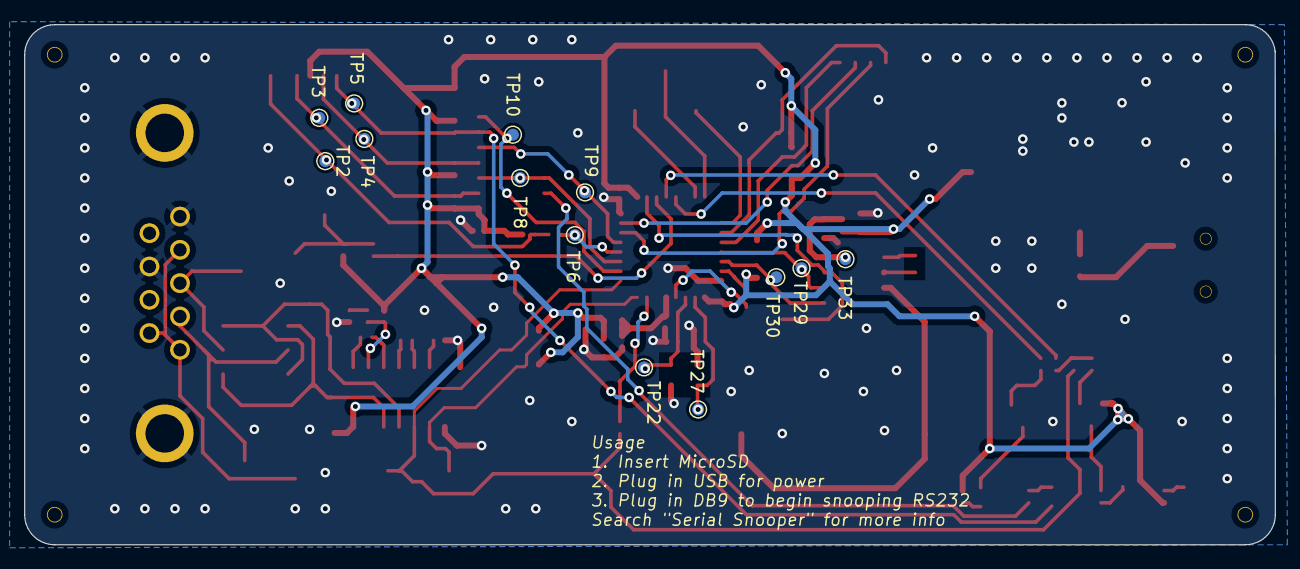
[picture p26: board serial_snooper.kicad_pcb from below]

Board: 2 copper layers, 104.0 x 43.2 mm, 101 parts (13 on the bottom side), 61 nets.

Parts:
C1: 10n; C_0402_1005Metric
C2, C3: 1u; C_0402_1005Metric
C4, C5, C6, C7, C12, C13, C14, C16, C17, C18, C19: 100n; C_0402_1005Metric
C8, C9: 15p; C_0402_1005Metric
C10, C11: 22u; C_0805_2012Metric
C15, C20, C21: 10u; C_0603_1608Metric
D1: GREEN; LED_0603_1608Metric
D3: RED; LED_0603_1608Metric
D4: RED_SD; LED_0603_1608Metric
D5: YELLOW; LED_0603_1608Metric
F2: 0ZCK0020FF2G; FUSC2214X100N
FB1: 120R; L_0603_1608Metric
H1, H2, H3, H4: MountingHole; ToolingHole
H5: 2894
IC1: 74HC4050D,653; SOIC127P600X175-16N
J1: Conn_01x03_Pin; PinHeader_1x03_P2.54mm_Vertical_SMD_Pin1Left
J2: Conn_01x05_Pin; PinHeader_1x05_P2.54mm_Vertical_SMD_Pin1Left
J5: L717SDE09P1ACH
J6: Micro_SD_Card_Det1; 5025700893
J8: USB_B_Mini; USB-MINI-10033526-N3212LF
Q1: MMBT3904; SOT-23
Q2: MMBT3906; SOT-23
R1, R3, R4, R5, R6: 10k; R_0402_1005Metric
R2, R12, R18, R23, R26: 1k5; R_0402_1005Metric
R7, R10: DNP; R_0402_1005Metric
R8, R27: 330R; R_0402_1005Metric
R9: 0R; R_0805_2012Metric
R11, R24, R25, R28: 0R; R_0402_1005Metric
R13, R14, R15, R16, R17, R19, R20: 47k; R_0402_1005Metric
R21, R22: 10K; R_0402_1005Metric
SW1: SW_DIP_x04; SW_DIP_SPSTx04_Slide_Omron_A6H-4101_W6.15mm_P1.27mm
SW2: SW_DPDT_x2; DPDT-SMD-MS-22D28G2-B
TP1, TP2, TP3, TP4, TP5, TP6, TP7, TP8, TP9, TP10, TP11, TP12, TP13, TP14, TP15, TP16, TP17, TP22, TP25, TP27, TP29, TP30, TP33, TP34, TP35: TestPoint; TestPoint_Pad_D1.0mm
U1: STM32F303K8T6; LQFP-32_7x7mm_P0.8mm
U2: AMS1117-3.3; SOT-223-3_TabPin2
U3: MAX3232; SOIC-16_3.9x9.9mm_P1.27mm
U4: PCF8523T; SOIC-8_3.9x4.9mm_P1.27mm
Y1: 16MHz; Crystal_SMD_3225-4Pin_3.2x2.5mm
Y2: 32.768; Crystal_SMD_2012-2Pin_2.0x1.2mm

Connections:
+3.3V: C3.1, C4.2, C11.1, C13.2, C15.1, C16.1, C17.1, C18.1, C19.1, C20.1, FB1.1, IC1.1 (VCC), J2.1, J6.4 (VDD), Q2.2 (E), R2.1, R3.1, R4.1, R5.1, R6.1, R8.2, R13.1, R14.1, R15.1, R16.1, R17.1, R19.1, R20.1, R21.1, R22.1, R23.2, U1.1 (VDD), U1.17 (VDD), U2.2 (VO), U3.16 (VCC)
+3.3VA: C1.1, C2.1, FB1.2, U1.5 (VDDA)
/BOOT0: R1.2, U1.31 (BOOT0)
/CARD_DETECT: R25.1, TP7.1, U1.19 (PA9)
/COMMS_LED: R7.1, U1.20 (PA10)
/DIPSWITCH_1: R6.2, SW1.1, U1.28 (PB5)
/DIPSWITCH_2: R5.2, SW1.2, U1.15 (PB1)
/DIPSWITCH_3: R4.2, SW1.3, U1.14 (PB0)
/DIPSWITCH_4: R3.2, SW1.4, U1.27 (PB4)
/HSE_IN: C8.1, TP27.1, U1.2 (PF0), Y1.1
/HSE_OUT: C9.1, TP22.1, U1.3 (PF1), Y1.3
/I2C1_SCL: R21.2, TP29.1, U1.29 (PB6), U4.6 (SCL)
/I2C1_SDA: R22.2, TP30.1, U1.30 (PB7), U4.5 (SDA)
/NRST: C7.1, U1.4 (NRST)
/PWR_LED_C: D1.2 (A), R2.2
/RS232-UART/C1+: C5.1, U3.1 (C1+)
/RS232-UART/C1-: C5.2, U3.3 (C1-)
/RS232-UART/C2+: C6.1, U3.4 (C2+)
/RS232-UART/C2-: C6.2, U3.5 (C2-)
/RS232-UART/DB9_RXD: J5.2, SW2.5 (B), TP12.1
/RS232-UART/DB9_TXD: J5.3, SW2.2 (B), TP11.1
/RS232-UART/R1IN: SW2.1 (A), SW2.6 (C), TP14.1, U3.13 (R1IN)
/RS232-UART/T1OUT: SW2.3 (C), SW2.4 (A), TP13.1, U3.14 (T1OUT)
/RS232-UART/VS+: C4.1, R10.1, U3.2 (VS+)
/RS232-UART/VS-: C12.2, U3.6 (VS-)
/RTC_IRQ: TP34.1, U1.18 (PA8), U4.7 (~INT1/CLKOUT)
/RealtimeClock/Battery+: H5.1 (+), H5.2 (-), U4.3 (VBAT)
/RealtimeClock/RTC_Vdd: C21.1, R23.1, TP33.1, U4.8 (VDD)
/SD-card-adapter/SD_CLK: IC1.2 (1Y), J6.5 (CLK), R14.2, TP3.1
/SD-card-adapter/SD_CS: D4.1 (K), IC1.6 (3Y), J6.2 (DAT3/CD), R16.2, TP5.1
/SD-card-adapter/SD_DETECT: J6.9 (DET), R17.2, R25.2, TP1.1
/SD-card-adapter/SD_DI: IC1.4 (2Y), J6.3 (CMD), R15.2, TP4.1
/SD-card-adapter/SD_DO: J6.7 (DAT0), R13.2, R24.2, TP2.1
/SD-card-adapter/SD_LED_ANODE: D4.2 (A), R18.2
/SPI1_CLK: IC1.3 (1A), IC1.14 (6A), TP8.1, U1.11 (PA5)
/SPI1_CS: IC1.7 (3A), TP10.1, U1.10 (PA4)
/SPI1_MISO: R24.1, TP6.1, U1.12 (PA6)
/SPI1_MOSI: IC1.5 (2A), TP9.1, U1.13 (PA7)
/STATUS_LED: R12.2, U1.21 (PA11)
/SWCLK: J2.3, U1.24 (PA14)
/SWDIO: J2.2, U1.23 (PA13)
/TIM2_CH2: R28.2, U1.7 (PA1)
/TRACE_SWO: J2.4, U1.26 (PB3)
/USART2_RX: J1.1, R11.1, R20.2, R28.1, TP16.1, U1.9 (PA3), U3.12 (R1OUT)
/USART2_TX: J1.3, R19.2, TP15.1, U1.8 (PA2), U3.11 (T1IN)
/VBUS_after_fuse: C10.1, F2.2, TP25.1, U2.3 (VI)
GND: C1.2, C2.2, C3.2, C7.2, C8.2, C9.2, C10.2, C11.2, C12.1, C13.1, C14.2, C15.2, C16.2, C17.2, C18.2, C19.2, C20.2, C21.2, D1.1 (K), D5.1 (K), H5.MP1, IC1.8 (GND), IC1.9 (4A), IC1.11 (5A), J1.2, J2.5, J5.5, J5.8, J5.MH1, J5.MH2, J6.6 (VSS), J6.10 (SHIELD), J8.5 (GND), J8.6 (Shield), Q1.2 (E), R1.1, SW1.5, SW1.6, SW1.7, SW1.8, TP35.1, U1.16 (VSS), U1.32 (VSS), U2.1 (GND), U3.8 (R2IN), U3.10 (T2IN), U3.15 (GND), U4.4 (VSS), Y1.2, Y1.4
unnamed: C14.1, R10.2
unnamed: D3.2 (A), R8.1
unnamed: D3.1 (K), Q1.3 (C)
unnamed: D5.2 (A), R27.1
unnamed: F2.1, R9.2
unnamed: IC1.15 (6Y), R18.1
unnamed: J5.1, J5.4, J5.6, TP17.1
unnamed: J8.1 (VBUS), R9.1
unnamed: Q1.1 (B), R12.1
unnamed: Q2.1 (B), R26.1
unnamed: Q2.3 (C), R27.2
unnamed: R7.2, R11.2, R26.2
unnamed: U4.1 (OSCI), Y2.1
unnamed: U4.2 (OSCO), Y2.2

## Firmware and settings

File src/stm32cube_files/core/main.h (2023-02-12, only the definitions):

#define CMX_FATFS       (1U << 0)
#define CMX_UART        (1U << 1) // with interrupt
#define CMX_I2C         (1U << 2)
#define CMX_UART_POLL   (1U << 3)
#define CS_I2C_SPI_Pin GPIO_PIN_3
#define CS_I2C_SPI_GPIO_Port GPIOE
#define PC14_OSC32_IN_Pin GPIO_PIN_14
#define PC14_OSC32_IN_GPIO_Port GPIOC
#define PC15_OSC32_OUT_Pin GPIO_PIN_15
#define PC15_OSC32_OUT_GPIO_Port GPIOC
#define PH0_OSC_IN_Pin GPIO_PIN_0
#define PH0_OSC_IN_GPIO_Port GPIOH
#define PH1_OSC_OUT_Pin GPIO_PIN_1
#define PH1_OSC_OUT_GPIO_Port GPIOH
#define OTG_FS_PowerSwitchOn_Pin GPIO_PIN_0
#define OTG_FS_PowerSwitchOn_GPIO_Port GPIOC
#define PDM_OUT_Pin GPIO_PIN_3
#define PDM_OUT_GPIO_Port GPIOC
#define B1_Pin GPIO_PIN_0
#define B1_GPIO_Port GPIOA
#define I2S3_WS_Pin GPIO_PIN_4
#define I2S3_WS_GPIO_Port GPIOA
#define SPI1_SCK_Pin GPIO_PIN_5
#define SPI1_SCK_GPIO_Port GPIOA
#define SPI1_MISO_Pin GPIO_PIN_6
#define SPI1_MISO_GPIO_Port GPIOA
#define SPI1_MOSI_Pin GPIO_PIN_7
#define SPI1_MOSI_GPIO_Port GPIOA
#define SD_CS_Pin GPIO_PIN_4
#define SD_CS_GPIO_Port GPIOA
#define SD_SPI_HANDLE hspi1

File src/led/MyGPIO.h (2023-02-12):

#ifndef MYGPIO_H
#define MYGPIO_H

#include <stm32f303x8.h>
#include "MyCommon.h"

// TODO, move to common?
typedef enum
{
    GPIO_INPUT = 0UL,
    GPIO_OUTPUT = 1UL,
    GPIO_ALT = 2UL,
    GPIO_MODE_MASK = 3UL
} GPIO_Mode_e;

// TODO, move to common?
typedef enum
{
    GPIO_LOW = 0,
    GPIO_HIGH = 1,
} GPIO_State_e;

typedef enum
{
    GPIO_PUSH_PULL,
    GPIO_OPEN_DRAIN,
} GPIO_OutputType_e;

typedef enum
{
    GPIO_PUPD_NONE = 0x0,
    GPIO_PUPD_UP   = 0x1,
    GPIO_PUPD_DOWN = 0x2,
    GPIO_PUPD_MASK = 0x3
} GPIO_PullUpDown_e;

typedef struct MyGPIO
{
    GPIO_TypeDef* gpio_register;
    GPIO_Pin_Mask_t pin_mask;
    GPIO_Mode_e mode;
    GPIO_ALTF_e alt_func;
    GPIO_OutputType_e output_type;
    GPIO_PullUpDown_e pupd;
} MyGPIO;

Error_Code_e MyGPIO_Init(const MyGPIO* gpio);
Error_Code_e MyGPIO_Write(GPIO_TypeDef* gpio_reg, GPIO_Pin_Mask_t pin_mask, GPIO_State_e high);
GPIO_State_e MyGPIO_Read(GPIO_TypeDef* gpio_reg, GPIO_Pin_Number_e pin);

#endif // MYGPIO_H

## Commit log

2022-07-05 fixed gpio not init tests, added test for all gpios
    [MyCommon.h, MyGPIO.c, MyGPIO.h]
2022-07-17 chore: remove cached and staged files for gitignore to work
2022-07-31 refactor: MyGPIO init returns error code now
    [MyCommon.h, MyGPIO.c, MyGPIO.h]
2022-07-31 refactor: GPIO pin mask is now a typedef uint16. Passes on STM32.
    This is due to the disparity between the dev PC and STM32 compilers. The STM32 compiler enums happened to be 16 bits, dev PC 32 bits. now the
    type size is equal on both devices. The test that used to check this has been removed and another added, see diff.
    No longer checking size of mask as it is now protected by the size of
    uint16.
    [MyCommon.c, MyCommon.h, MyGPIO.c]
2022-08-01 refactor: change name for gpio mask as its no longer enum
    [MyCommon.c, MyCommon.h, MyGPIO.c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]
2022-08-21 feat: uart read/write 1 byte. start CLI tests
2022-09-03 test: add terminal UART wrapper module
2022-09-04 test: MyReceiver now uses new Terminal module and doesnt access uart directly
2022-09-04 test: add main. change \n to \r. add TODOS for UART
2022-10-02 add stm32 HAL fake headers, ceedling compiles
2022-10-02 add fake headers for LED module. now can call mock HAL calls
2022-10-02 led module init uses fake HAL directly - passes all tests
2022-10-02 refactor: button init calls HAL directly and not adapter
2022-10-02 refactor: use HAL NVIC directly for button. update yaml file- but doesn't seem to make difference
2022-10-02 refactor: remove gpio hal adapter from button module but keep the interrupt related functions (and changed name of this adapter to something more meaningful)
2022-10-29 migrate: update stm32 libraries, ide paths & updating implementations to match new processor
2022-10-29 migrate: replace fatfs core files for stm32f0, replace cubeMX generated code
2022-10-29 migrate: compiles now that HAL DMA & Cortex are included, and ITM removed (no ITM on F0)
2022-10-29 migrate: update tests. all passes now
    required some changes to the yml file and updates to some references to
    defined used in stm32 libraries.
2022-10-30 migrate: update test fakes and the new gpios for this board. fix warnings
    [LED.c, MyCommon.h, MyTerminalUART.c]
2022-10-30 migrate: update button nvic function - unit tests and manual target test passes
2022-10-30 refactor: remove 'hardware' TDD tests as no longer using them and tidy RCC module
    [MyCommon.h, MyTerminalUART.c]
2022-10-30 feat: add dip switch module
2022-10-30 feat: add DIP switch module reads to CLI
2022-10-30 feat: add LED to CLI
2022-11-06 feat: add UART from CubeMX
2022-11-06 test: change include guard to use the same one as STM32 for _hal_def.h
2022-11-08 feat: snooping app uart on interrupt, saves to circular buffer
2022-11-09 feat: do tdd for serial snooper app and more...
    - uart irq just saves incoming data to circular buffer, doesnt do any
    processing
    - the processing is done by the serial snooper app, i.e. add timestamp
    - the MySD module now controls LED too
    - serial snooper shall flush the sd card every 500 ms
    - !! the serial snooper tests need to be refactored. !!
2022-11-09 feat: add i2c driver from cubemx
2022-11-10 fix: RTC seconds now correct. add getTime to CLI. low level init now the responsibility of modules (except fatfs for now)
    [MyRTC.c]
2022-11-11 fix: warnings on RTC module
    [MyRTC.c]
2022-11-11 optimise: CLI to use HAL UART (deleted my CMSIS one) to save space
2022-11-11 feat: baud rate is decided at boot via dip switches
2022-11-11 feat: toggle LED in HAL error handler. max BR is no longer 960k as init fails
2022-11-14 fix: uart and i2c pulled up to prevent bad data to peripherals and circ buffer no longer overwrites. instead it will not fill it in
    [MyCommon.h]
2022-11-14 refactor: move DIP switch init typedef to stack to save RAM
2022-11-14 refactor: optimise time stamp use lookup instead of printf and reduce size of timestamp itself
2022-11-19 fix: read RTC only if 1 second has elapsed since last i2c read
    [MyRTC.c]
2022-11-19 optimise: Remove some CLI commands: LED, SD, Circ Buffer
2022-11-19 optimise: remove calls to MyGPIO module as its no longer needed. Remove controller module.
    [MyDipSwitch.c, MyTerminalUART.c]
2022-11-19 docs: update readme with more prototype board details
2022-11-20 feat: spi speed for sd card increased to 18 MHz (from less than 1 MHz)
2022-11-20 fix: init RTC with updated power management: direct switching mode
    [MyRTC.c]
2022-11-21 fix: link to final report on readme + update prototype img
2023-01-08 docs: Update README as no more data losses
    Increasing SPI clock speed to maximum meant no data is lost currently. Had to update README which was still mentioning data losses.
2023-01-21 chore: only include *hal.h for led as suggested by HAL driver docs
2023-01-21 feat: indicate via LED when data is lost
    Red LED on pin A11 will light up if data is lost. it remains on until uC
    is reset.
    [MyCommon.h]
2023-01-28 refactor: move across tests for the operation of write/flush sd
    they go in their own module and own functions.
    this is one of the steps of separating the
    operations in the SerialSnooper_Run into their own module
    and individual functions.
    the tests were made very complicated simply because of
    the fact that the Run() function was doing too many things at once.
    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
2023-01-29 (to squash) just saving as system is working currently but tests won't pass as I'm rewriting serial snooper
2023-01-29 refactor: (in progress) remove reliance on hal for timer
2023-02-12 migrate to stm32f303k8 from stm32f031k6
    compiles but not tested on target.
    - updated files
    - change i2c1 pins from pa9,10 to pb6,7
    - change usart from usart1 to usart2 and update alt function value
    - update spi1 alt func value
    - remove PREDIV assignment in RCC typedef as new driver doesnt have it
2023-02-19 fix: update usart, spi and clock speeds. sd card doesnt init however. comitting to save checkpoint
2023-02-20 fix: increase processor and SPI speed, remove i2c
    - APB2 bus at 72 MHz
    - SPI at 36 MHz
    - I2C pins were conflicting with SPI pins due to a solder bridge on the
    F3 nucleo. Removed them temporarily. The plan is to use internal RTC
    anyway so there won't be a need for I2C line.
2023-02-21 feat: circular buf size increased from 8192 to 10300
    circular buffer no longer has to be power of 2. the speed difference
    appears to be negligible.
    reduced stack and heap size to accomodate increase of circ buffer size
2023-02-23 docs: add profiling spreadsheet
    [FatFS Profiling.xlsx]
2023-02-25 fix: significantly improve block write speed, update version num to 2
    - logic analyser inspection showed that for every byte transferred,
    which takes 1us, there was a 14 us delay. The low user_diskio_spi.c
    driver was sending bytes 1 at a time via the HAL API. Updated it to
    send multi bytes. Transfer rate has more than doubled.
    - update version number to 2
2023-02-25 fix: re-enable I2C now that the wiring is done
    + tidy comments
2023-04-07 test: start redoing MySD tests - add fake led
2023-04-08 test: fakeff file open fails if file was already open
    test: add f_close to fakeff file
    test: fakeff f_sync and f_close will fail if file not open
    test: fakeff f_close will flush contents of file buffer
    test: MySD tests for LED turning on and opening consecutive files
2023-04-08 test: fakeff mounting twice causes error
    test: fakeff file size is now correct for a file that already existed
    test: MySD tests for when opening a file fails - led should remain off
2023-04-16 test: MyApp tests updated.
    Separated MyApp to two: init and infinite loop
    Made READ_FILE macro visible to other tests.
    Add fakefilesystem dump function to print contents.
    Tidied SystemOperations
    + Add some helpers
2023-04-16 refactor: move flush schedule responsibility to scheduler + test on board
    instead of SystemOperations. as that's that the scheduler is for
2023-04-22 feat: remembers last log file opened on powerup
    using stm32 flash to store log file name and retriveving it upon start
    up.
    added boilerplate code for flash access and the fakes for it.
2023-05-11 hardware: do PCB design
    hardware: basic circuitry (power supply not yet connected)
    hardware: tidied schematic
    hardware: add leds, dip switch and headers
    hardware: add rs232-uart section
    hardware: sd card interface
    hardware: wire up SPI, add pullups to comms lines. add led to sd card clk
    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
    [0ZCK0020FF2G.SchLib, 0ZCK0020FF2G.stp, 10033526-N3212LF--3DModel-STEP-554624.STEP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]
2023-05-16 feat: auto baud rate (sw seemingly ready but hw not working)
    - add new abstractions: MyUART, autobaudrate, MyTimer
    - add fakes for the HW dependent abstractions (MyUART and MyTimer)
    - add tests to ensure autobaudrate works based on an input capture
    - add tests to MyApp to ensure UART is configured with the correct baud
    rate
    all tests passing however HW tests show that the timer isn't
    triggering.
    [MyUART.c]
2023-05-21 feat: basic auto baud rate working
    - tested with 200 to 460k baud rate and it works.
    - requires further thorough testing to ensure it's reliable
    - decide whether or not we want the baud rate to be configurable on the fly
    - work on optimisations i.e. turn off timer interrupt when baud rate acquired
    - i've noticed sometimes baud rate is not correct - need to reliably repeat and fix issue
2023-06-24 fix: update code to match PCB
    - remove pullup on DIP switch as we have hardware pullups
    - light up the "info" led when SD card is detected. the "save" led isn't
    lighting, I think the current limiting resistor is too large.
    - remove error_indicator LED. we will use the "info" led for that
    function in the future once the blue LED resistor issue is fixed.
    hardware:
    - include more datasheets that have been useful
    - update hw files (with fix on the gerber file)
    [serial_snooper-B_Cu.gbr, serial_snooper-B_Mask.gbr, serial_snooper-B_Paste.gbr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]
2023-07-30 hardware: add interactive bom html file to aid soldering

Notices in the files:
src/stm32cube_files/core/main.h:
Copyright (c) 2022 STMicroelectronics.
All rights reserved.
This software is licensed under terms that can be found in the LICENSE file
